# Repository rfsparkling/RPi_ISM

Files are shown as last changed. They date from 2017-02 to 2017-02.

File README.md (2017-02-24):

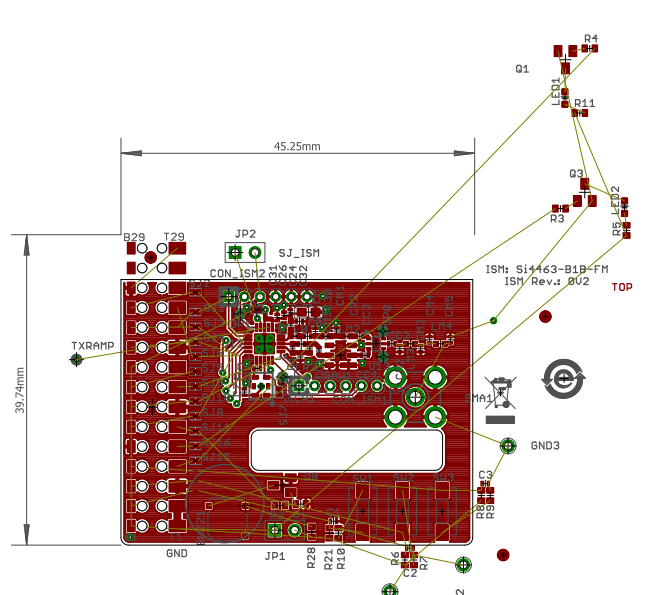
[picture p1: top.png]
layout preview


RPi ISM is a ISM radio shield / module for all the RaspberryPi versions. The schematic finished the layout is about 90% finished yet.

Validated Eagle Parts in this project:

Silabs ISM radio
Si4463-B1B-FM
https://www.silabs.com/documents/public/data-sheets/Si4464-63-61-60.pdf

SAW filter
B39871B3725U410
http://www.mouser.com/ds/2/400/B3725-525464.pdf

TCXO
KT2520F26000ACW18TAN
http://www.mouser.com/ds/2/40/kt2520_gps_e_2012-838160.pdf

RF switch
UPG2214TB-A
http://www.cel.com/pdf/datasheets/upg2214tb.pdf

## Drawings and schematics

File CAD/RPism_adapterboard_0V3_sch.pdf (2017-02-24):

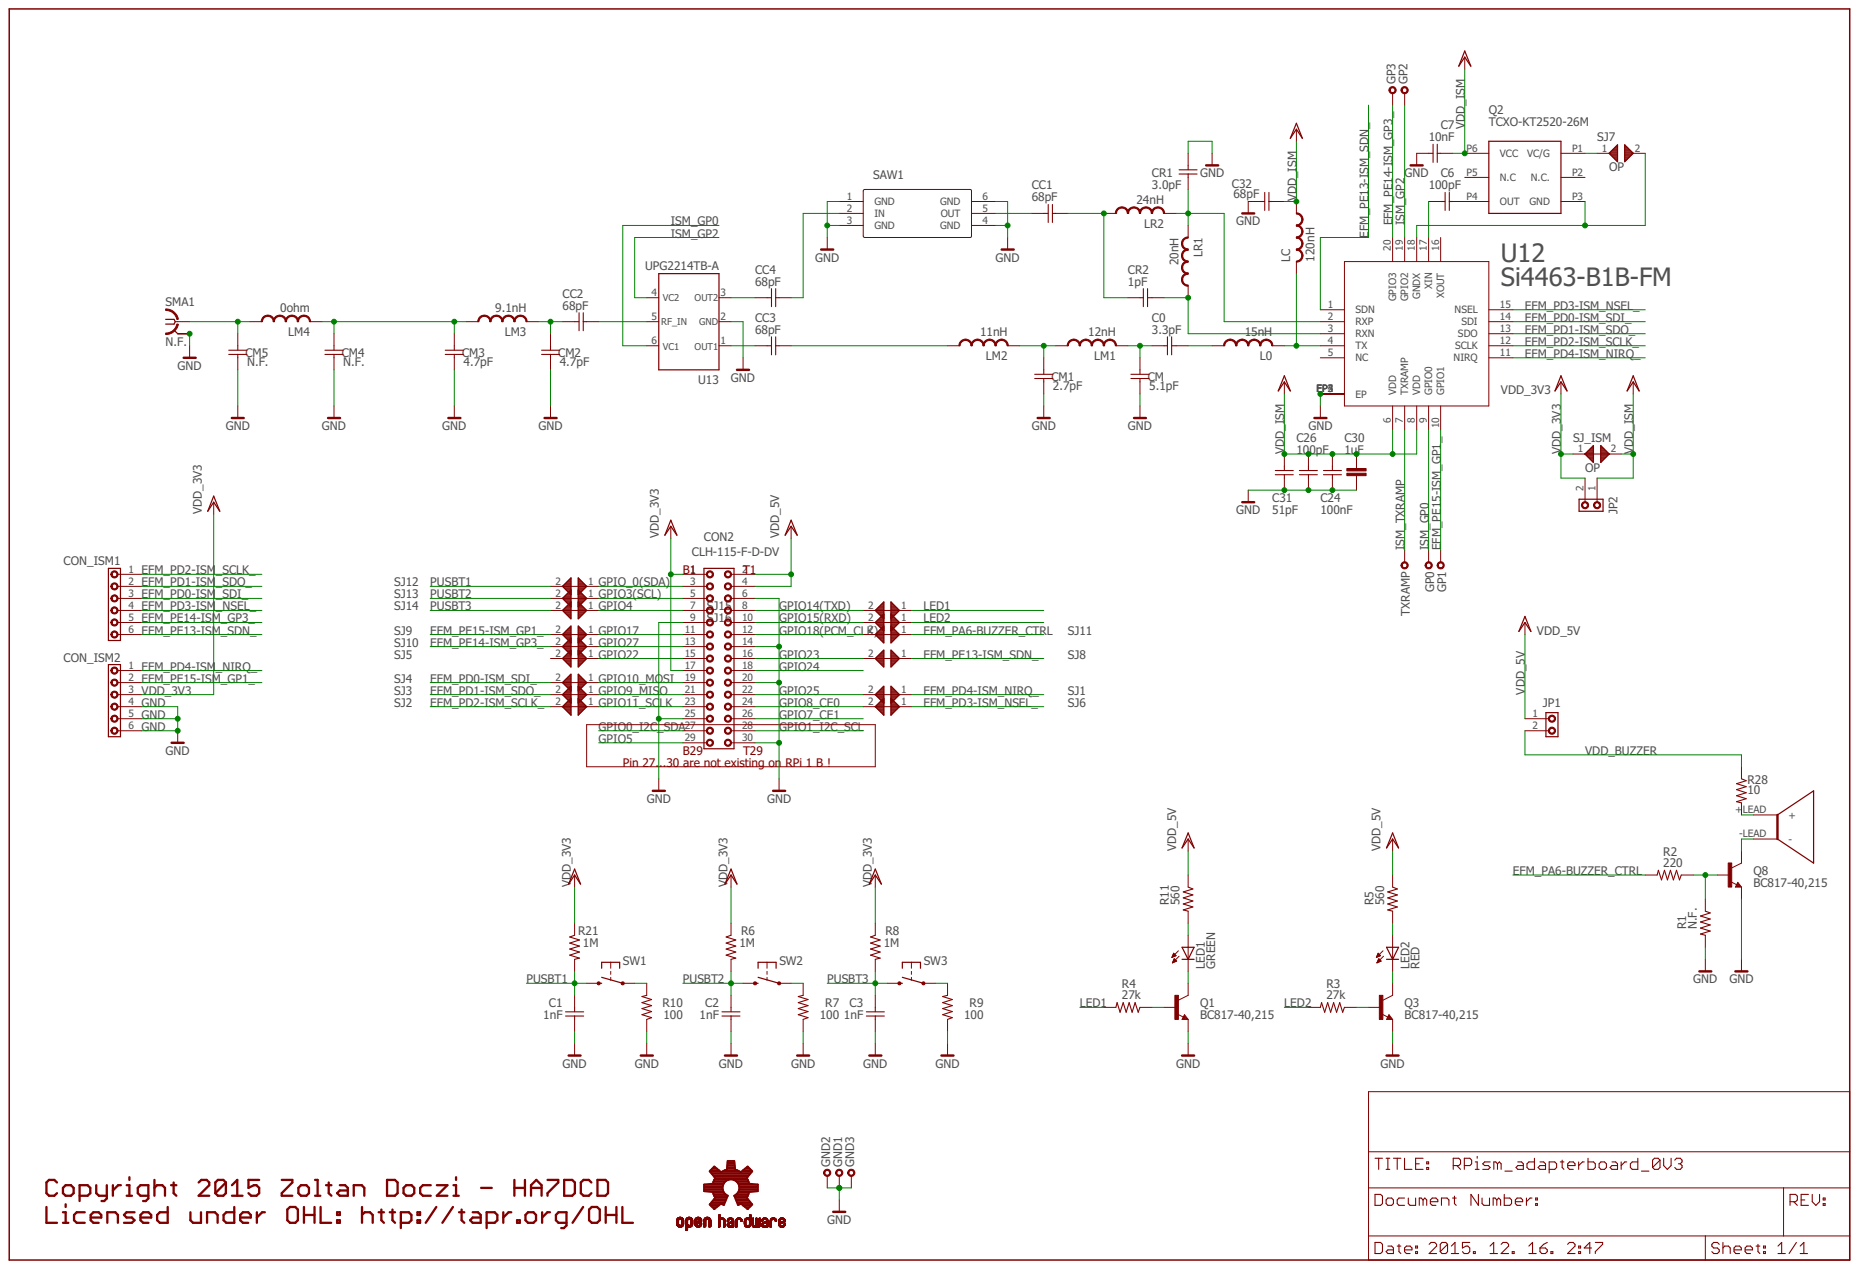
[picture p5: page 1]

Pin 27...30 are not existing on RPi 1 B !

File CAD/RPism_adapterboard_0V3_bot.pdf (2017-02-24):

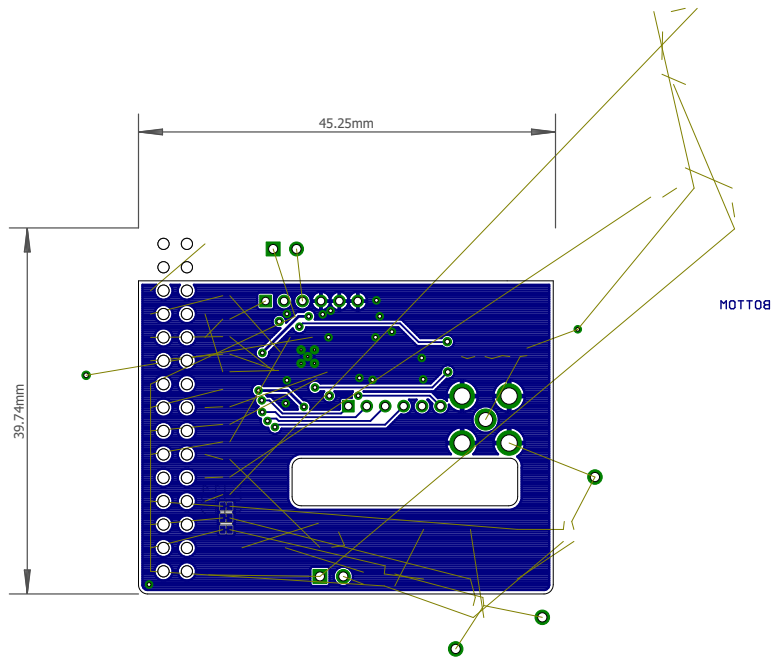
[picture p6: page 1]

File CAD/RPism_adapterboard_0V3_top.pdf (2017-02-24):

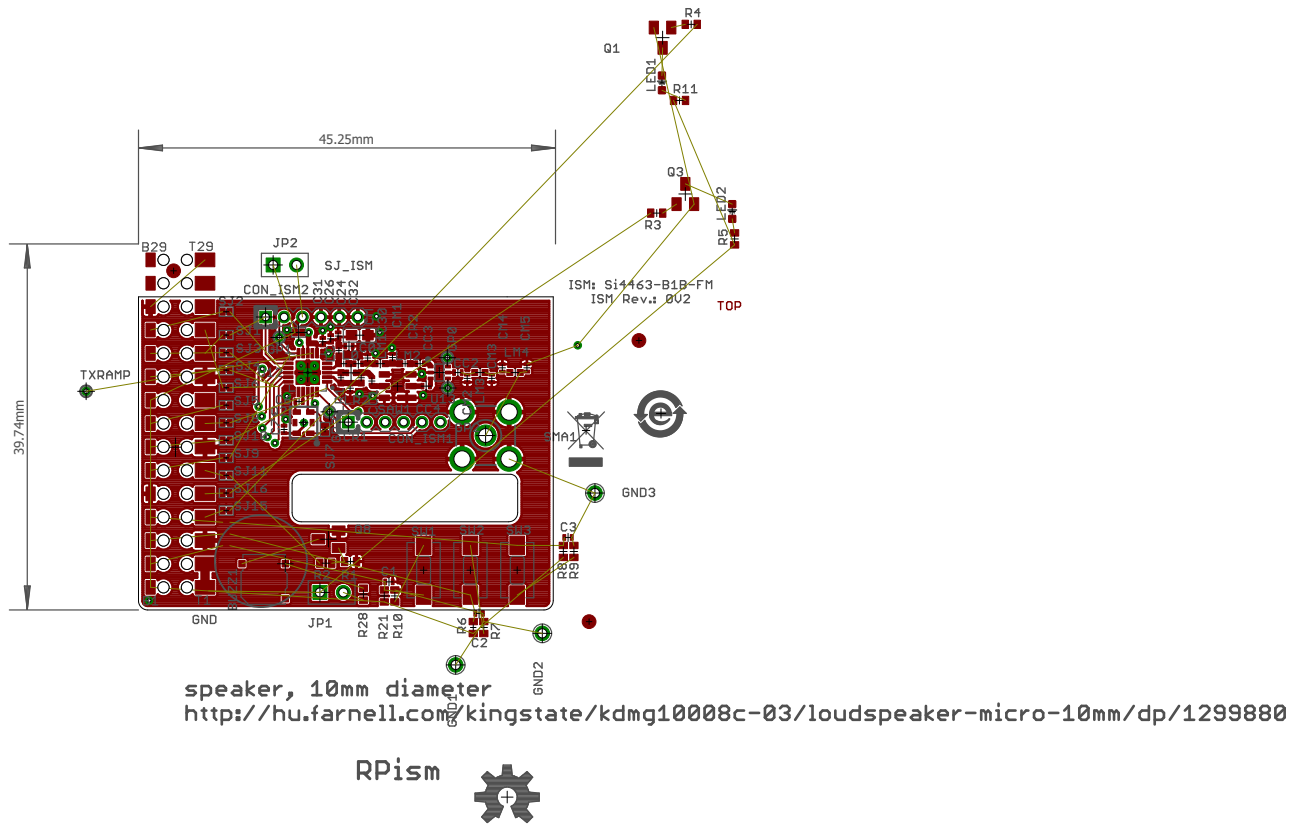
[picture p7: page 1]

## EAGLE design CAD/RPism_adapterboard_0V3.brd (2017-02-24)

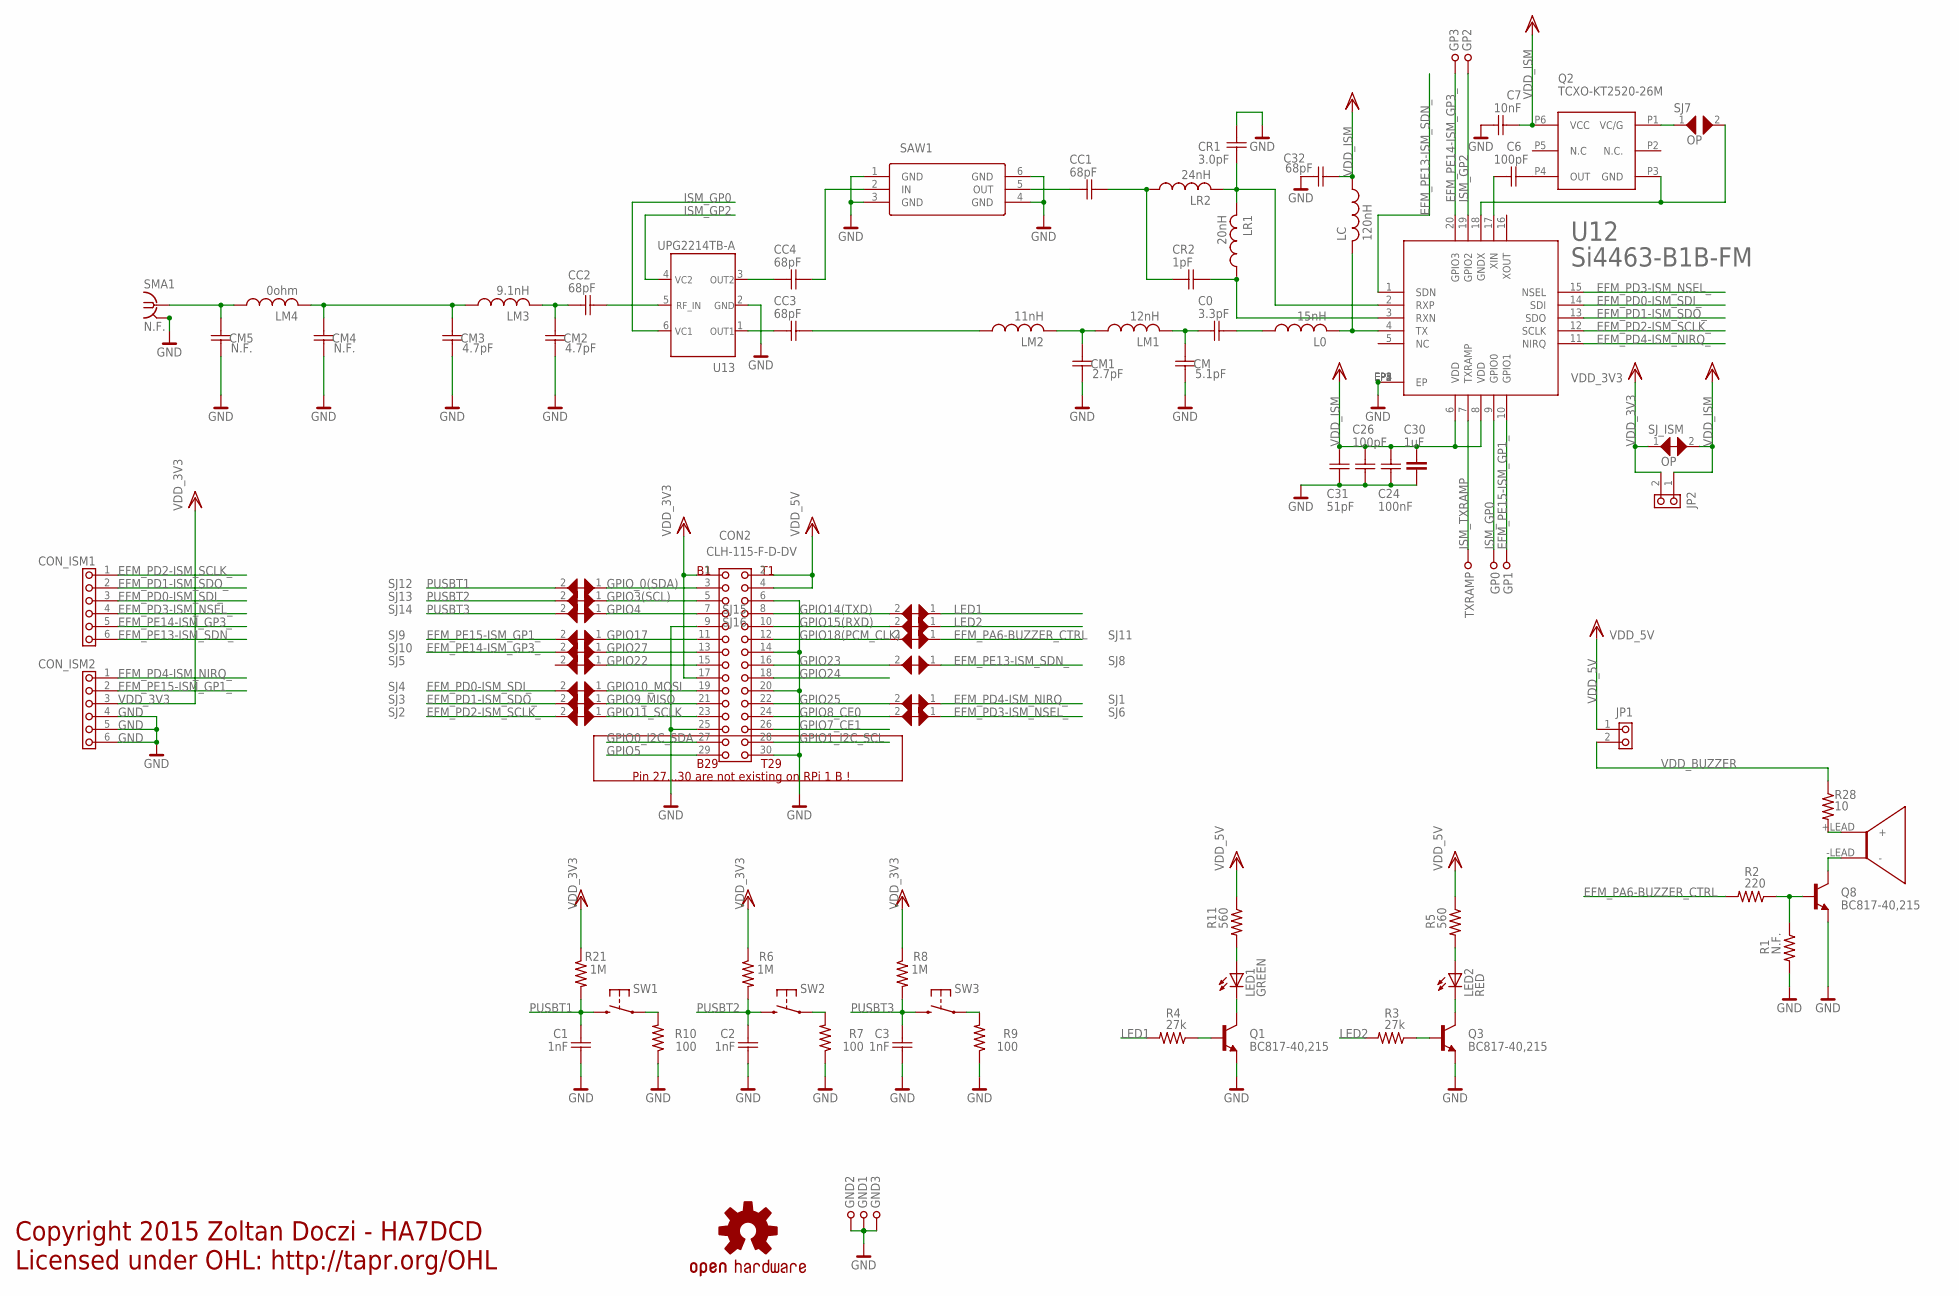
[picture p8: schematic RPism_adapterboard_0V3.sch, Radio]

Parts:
BUZZ1: SMT-0540-S-R
C0: 3.3pF; CAPC1005X60N
C1, C2, C3: 1nF; CAPC1005X60N
C6, C26: 100pF; CAPC1005X60N
C7: 10nF; CAPC1005X60N
C24: 100nF; CAPC1005X60N
C30: 1uF; 0603
C31: 51pF; CAPC1005X60N
C32: 68pF; CAPC1005X60N
CC1, CC2, CC3, CC4: 68pF; CAPC1005X60N
CM: 5.1pF; CAPC1005X60N
CM1: 2.7pF; CAPC1005X60N
CM2, CM3: 4.7pF; CAPC1005X60N
CM4, CM5: N.F.; CAPC1005X60N
CON2: CLH-115-F-D-DV; 2X15_SMT_CROSSPCB_ASSYM
CON_ISM1: MALE__PIN6S-2MM; PIN6S_2MM
CON_ISM2: FEMALE__PIN6S-2MM; PIN6S_2MM
CR1: 3.0pF; CAPC1005X60N
CR2: 1pF; CAPC1005X60N
GND1, GND2, GND3: TESTPOINT39MIL; TESTPOINT1,0
GP0, GP1, GP2, GP3: TESTPOINT20MIL; TESTPOINT0,5
JP1: JUMPER2; PIN2-1R
JP2: N.F.; PIN2-1R
L0: 15nH; 0402-INDUCT; PARTNR LQW15AN15NJ00
LC: 120nH; 0402-INDUCT; PARTNR LQW15ANR12J00
LED1: GREEN; LED-0603
LED2: RED; LED-0603
LM1: 12nH; 0402-INDUCT; PARTNR LQW15AN12NJ00
LM2: 11nH; 0402-INDUCT; PARTNR LQW15AN11NJ00
LM3: 9.1nH; 0402-INDUCT; PARTNR LQW15AN9N1J00
LM4: 0ohm; 0402-INDUCT; PARTNR LQW15AN12NJ00
LR1: 20nH; 0402-INDUCT; PARTNR LQW15AN20NJ00D
LR2: 24nH; 0402-INDUCT; PARTNR LQW15AN24NJ00D
Q1, Q3, Q8: BC817-40,215; SOT23-BEC
Q2: TCXO-KT2520-26M; TCXO_2.5X2MM
R1: N.F.; R0402
R2: 220; R0402
R3, R4: 27k; R0402
R5, R11: 560; R0402
R6, R8, R21: 1M; R0402
R7, R9, R10: 100; R0402
R28: 10; R0402
SAW1: SAW_EPCOS_B3725; DCC6C
SJ1, SJ2, SJ3, SJ4, SJ5, SJ6, SJ8, SJ9, SJ10, SJ11, SJ12, SJ13, SJ14, SJ15, SJ16: JUMPER_SMD_MICRO_SHORT
SJ7: OP; JUMPER_SMD_MICRO
SJ_ISM: OP; JUMPER_SMD_MICRO_SHORT
SMA1: N.F.; BU-SMA-V
SW1, SW2, SW3: DTSM_32N
TXRAMP: TESTPOINT20MIL; TESTPOINT0,5
U12: Si4463-B1B-FM; QFN-20_PRO2_VERIFIED
U13: UPG2214TB-A; 6-PIN_SUPER_MINIMOLD
U$15: OSHW-LOGOL; OSHW-LOGO-L

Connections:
EFM_PA6-BUZZER_CTRL: R2.2, SJ11.1
EFM_PD0-ISM_SDI_: CON_ISM1.3, SJ4.2, U12.14 (SDI)
EFM_PD1-ISM_SDO_: CON_ISM1.2, SJ3.2, U12.13 (SDO)
EFM_PD2-ISM_SCLK_: CON_ISM1.1, SJ2.2, U12.12 (SCLK)
EFM_PD3-ISM_NSEL_: CON_ISM1.4, SJ6.1, U12.15 (NSEL)
EFM_PD4-ISM_NIRQ_: CON_ISM2.1, SJ1.1, U12.11 (NIRQ)
EFM_PE13-ISM_SDN_: CON_ISM1.6, SJ8.1, U12.1 (SDN)
EFM_PE14-ISM_GP3_: CON_ISM1.5, GP3.1, SJ10.2, U12.20 (GPIO3)
EFM_PE15-ISM_GP1_: CON_ISM2.2, GP1.1, SJ9.2, U12.10 (GPIO1)
GND: C1.2 (C2), C2.2 (C2), C3.2 (C2), C7.1 (C1), C24.2 (C2), C26.2 (C2), C30.1, C31.2 (C2), C32.1 (C1), CM.2 (C2), CM1.2 (C2), CM2.2 (C2), CM3.2 (C2), CM4.2 (C2), CM5.2 (C2), CON2.6, CON2.9, CON2.14, CON2.20, CON2.25, CON2.30, CON_ISM2.4, CON_ISM2.5, CON_ISM2.6, CR1.1 (C1), GND1.1, GND2.1, GND3.1, Q1.E, Q3.E, Q8.E, R1.2, R7.1, R9.1, R10.1, SAW1.1 (GND), SAW1.3 (GND), SAW1.4 (GND), SAW1.6 (GND), SMA1.2, SMA1.3, SMA1.4, SMA1.5, U12.EP0 (EP), U12.EP1 (EP), U12.EP2 (EP), U12.EP3 (EP), U12.EP4 (EP), U12.EP5 (EP), U13.2
GPIO0_I2C_SDA: CON2.27
GPIO1_I2C_SCL: CON2.28
GPIO3(SCL): CON2.5, SJ13.1
GPIO4: CON2.7, SJ14.1
GPIO5: CON2.29
GPIO7_CE1: CON2.26
GPIO8_CE0: CON2.24, SJ6.2
GPIO9_MISO: CON2.21, SJ3.1
GPIO10_MOSI: CON2.19, SJ4.1
GPIO11_SCLK: CON2.23, SJ2.1
GPIO14(TXD): CON2.8, SJ15.2
GPIO15(RXD): CON2.10, SJ16.2
GPIO17: CON2.11, SJ9.1
GPIO18(PCM_CLK): CON2.12, SJ11.2
GPIO22: CON2.15, SJ5.1
GPIO23: CON2.16, SJ8.2
GPIO24: CON2.18
GPIO25: CON2.22, SJ1.2
GPIO27: CON2.13, SJ10.1
GPIO_0(SDA): CON2.3, SJ12.1
ISM_GP0: GP0.1, U12.9 (GPIO0), U13.6
ISM_GP2: GP2.1, U12.19 (GPIO2), U13.4
ISM_TXRAMP: TXRAMP.1, U12.7 (TXRAMP)
LED1: R4.2, SJ15.1
LED2: R3.2, SJ16.1
unnamed: Q1.B, R4.1
unnamed: LED1.C, Q1.C
unnamed: LED1.A, R11.2
unnamed: LED2.C, Q3.C
unnamed: LED2.A, R5.2
unnamed: Q3.B, R3.1
unnamed: R7.2, SW2.1
unnamed: C6.1 (C1), U12.17 (XIN)
unnamed: R9.2, SW3.1
unnamed: C6.2 (C2), Q2.P4 (OUT)
unnamed: R10.2, SW1.1
unnamed: BUZZ1.+LEAD (+), R28.2
unnamed: BUZZ1.-LEAD (-), Q8.C
unnamed: Q8.B, R1.1, R2.1
unnamed: CC1.1 (C1), SAW1.5 (OUT)
unnamed: Q2.P1 (VC/G), SJ7.1
unnamed: L0.2, LC.2, U12.4 (TX)
unnamed: C0.1 (C1), L0.1
unnamed: C0.2 (C2), CM.1 (C1), LM1.2
unnamed: CM1.1 (C1), LM1.1, LM2.2
unnamed: CC3.2 (C2), LM2.1
unnamed: CC3.1 (C1), U13.1
unnamed: CC2.2 (C2), U13.5
unnamed: CR2.1 (C1), LR1.1, U12.3 (RXN)
unnamed: CR1.2 (C2), LR1.2, LR2.2, U12.2 (RXP)
unnamed: Q2.P3 (GND), SJ7.2, U12.18 (GNDX)
unnamed: CC1.2 (C2), CR2.2 (C2), LR2.1
unnamed: CC4.2 (C2), SAW1.2 (IN)
unnamed: CC4.1 (C1), U13.3
PUSBT1: C1.1 (C1), R21.2, SJ12.2, SW1.2
PUSBT2: C2.1 (C1), R6.2, SJ13.2, SW2.2
PUSBT3: C3.1 (C1), R8.2, SJ14.2, SW3.2
RF3: CM5.1 (C1), LM4.1, SMA1.1
RF10: CC2.1 (C1), CM2.1 (C1), LM3.2
RF12: CM3.1 (C1), CM4.1 (C1), LM3.1, LM4.2
VDD_3V3: CON2.1, CON2.17, CON_ISM2.3, JP2.2 (B), R6.1, R8.1, R21.1, SJ_ISM.1
VDD_5V: CON2.2, CON2.4, JP1.1 (A), R5.1, R11.1
VDD_BUZZER: JP1.2 (B), R28.1
VDD_ISM: C7.2 (C2), C24.1 (C1), C26.1 (C1), C30.2, C31.1 (C1), C32.2 (C2), JP2.1 (A), LC.1, Q2.P6 (VCC), SJ_ISM.2, U12.6 (VDD), U12.8 (VDD)

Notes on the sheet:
Copyright 2015 Zoltan Doczi - HA7DCD Licensed under OHL: http://tapr.org/OHL
Pin 27...30 are not existing on RPi 1 B !

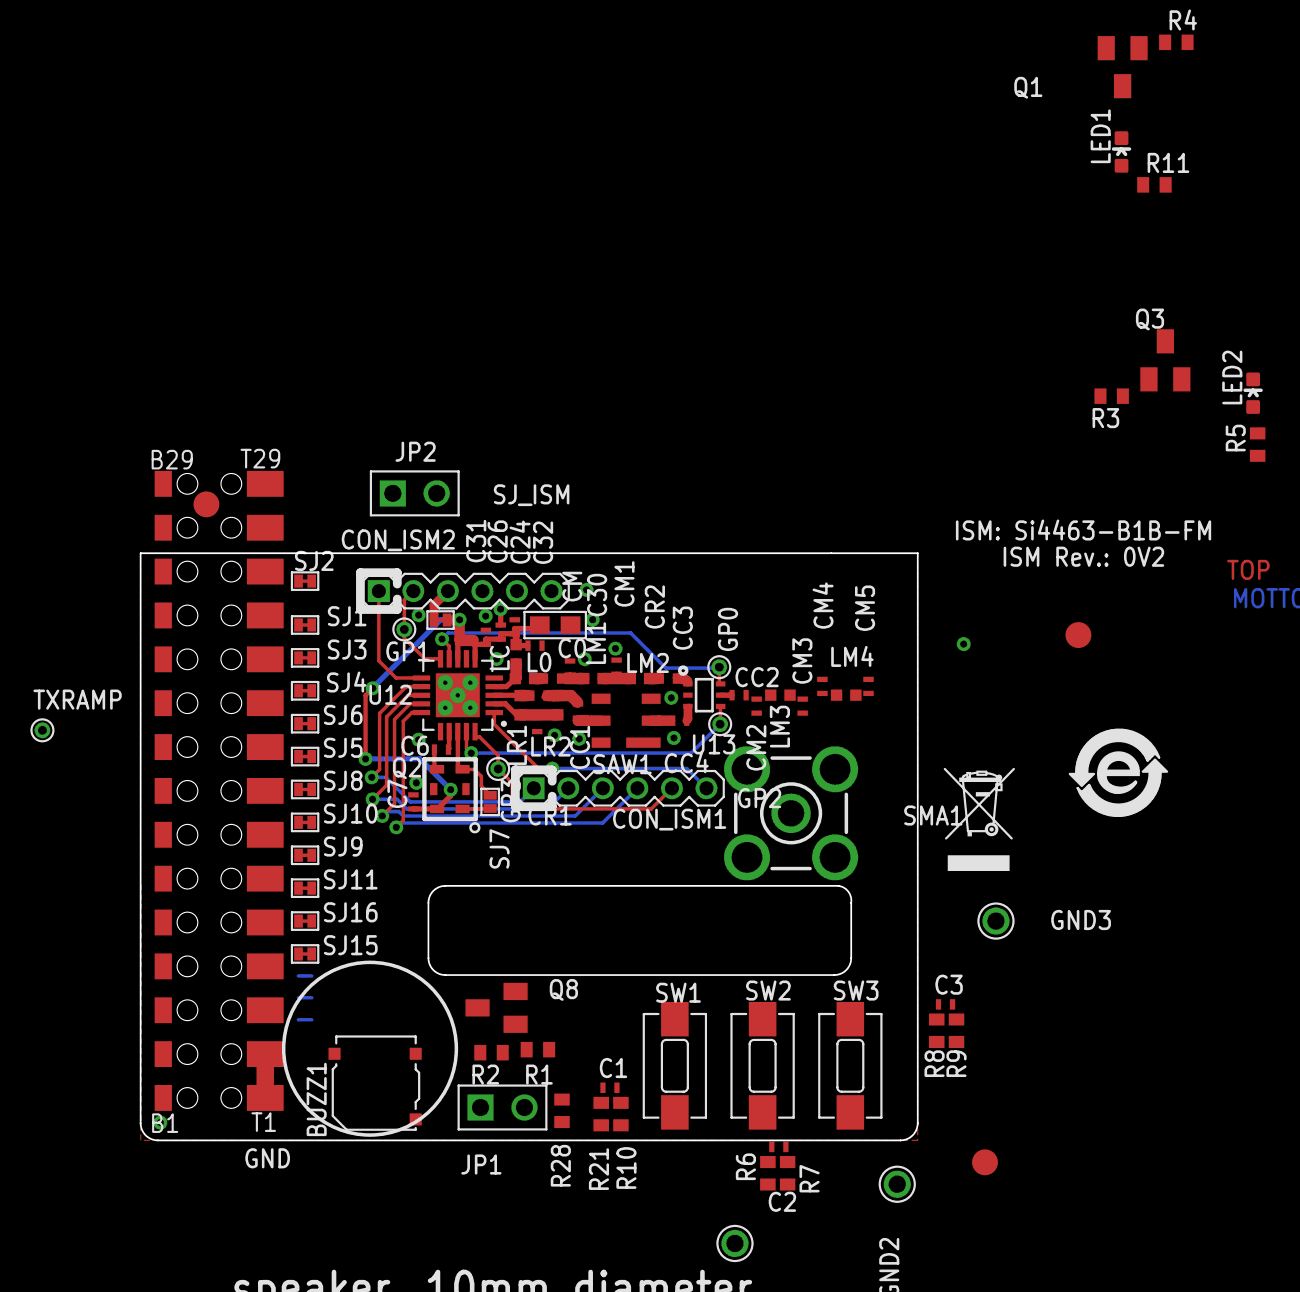
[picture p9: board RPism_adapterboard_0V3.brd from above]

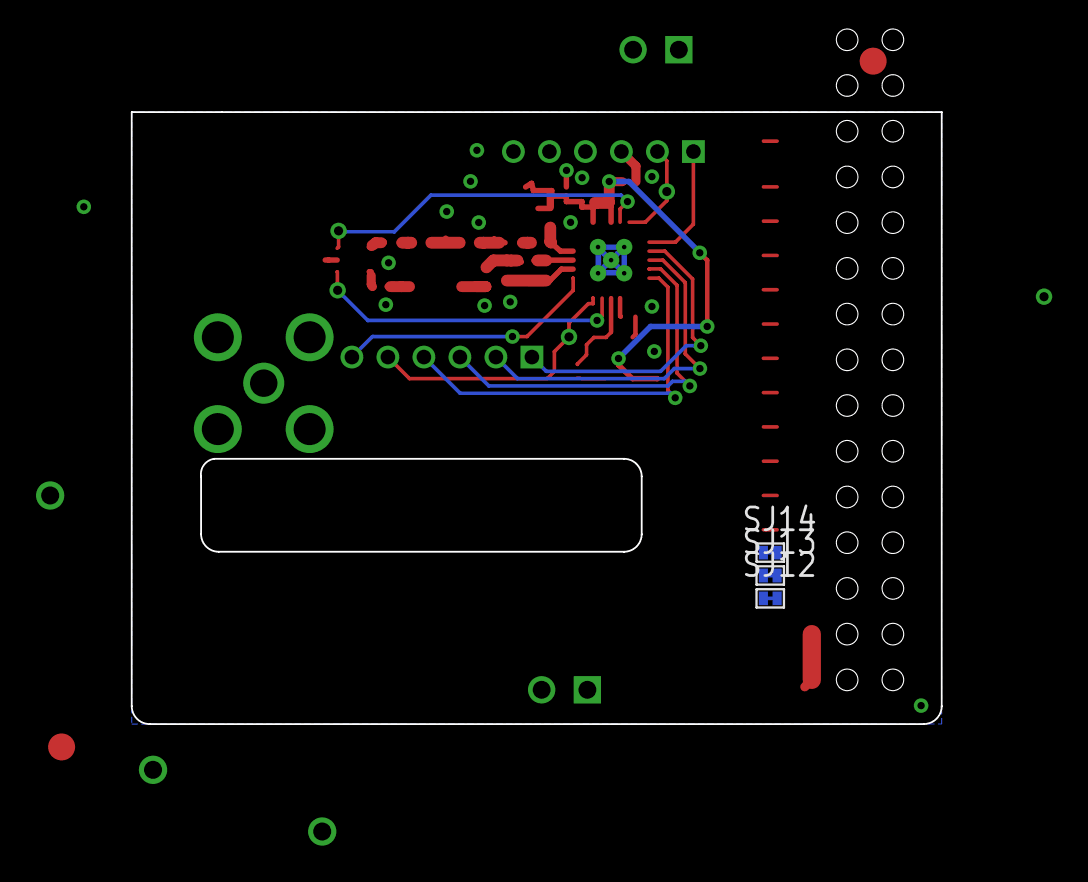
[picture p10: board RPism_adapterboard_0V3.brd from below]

Board: 2 copper layers, 45.0 x 34.0 mm, 94 parts (3 on the bottom side), 69 nets.

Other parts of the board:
U$1, U$115, U$116: FIDUCIAL
U$142: NON-DISPOSABLE
U$143: ROHS_CHINA

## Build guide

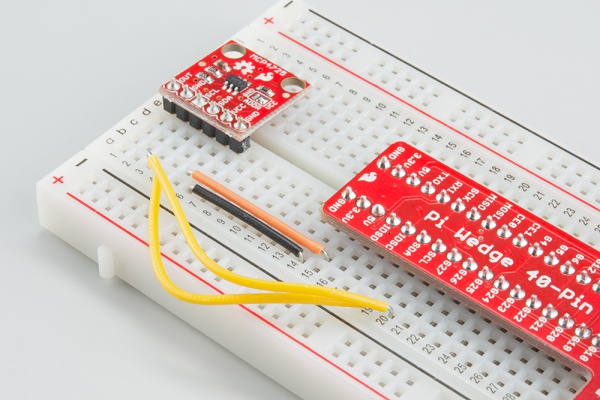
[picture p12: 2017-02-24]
datasheet/RPi_ISM_interfacing/Raspberry Pi SPI and I2C Tutorial - learn.sparkfun.com_files/i2c-sample.jpg

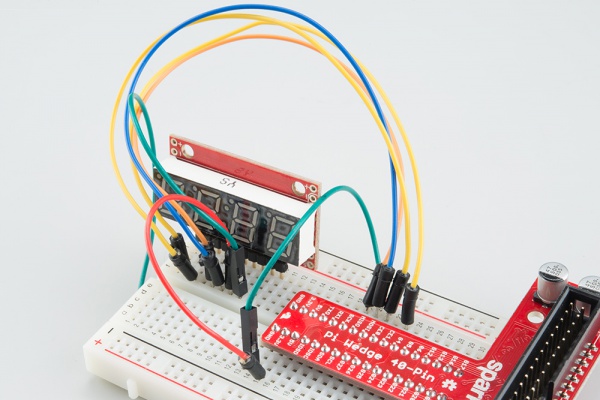
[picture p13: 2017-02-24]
datasheet/RPi_ISM_interfacing/Raspberry Pi SPI and I2C Tutorial - learn.sparkfun.com_files/spi-sample.jpg

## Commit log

2017-02-24 uploading 90% ready cad files + datasheets
    [RPism_adapterboard_0V3.brd, RPism_adapterboard_0V3.sch, RPism_buzzer_crossreference_file.xlsx]
2026-10-25 README: 3D render of RPi ISM v1 on a Raspberry Pi 3 B with 868 MHz antenna; note CON2 row mapping and cut-out arc to verify
    Claude-Session: https://claude.ai/code/session_01BJnEoxRuTcRQUC15fEuvqA
2026-10-25 README: drop CON2 row-mapping note (mounting proven on QRPi)
    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
2026-10-25 README: add QRPi on Raspberry Pi 1 photo
    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
2026-10-29 docs: clarify wM-Bus is received natively by the FG23 radio (RAIL wM-Bus PHYs), no I/Q
    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
